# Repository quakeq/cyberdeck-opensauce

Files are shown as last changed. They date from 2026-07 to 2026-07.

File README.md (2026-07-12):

# cyberdeck-opensauce
repo for my cyberdeck project for hackclub opensauce. I made this because I wanted to make an useable cyberdeck that would be genuinely really nice to have daily.

## Demo
https://drive.google.com/file/d/1zyx6e2210Nebm2rjT3ZHg2T8rBJLfXjD/view?usp=sharing

## features
- Storage for all your goodies
- Custom Battery with 10 hr lifespan
- Mechanical keyboard that's removable for access to wires and stuff.
- Watersealed Case
- 10.1 inch touchscreen
- 2 USB ports and 1 ethernet

## Some images of the design and final product:





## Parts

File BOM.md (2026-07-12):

| Name | Quantity | Links |
|---|---|---|
| 10.1 DSI screen | 1 | https://www.waveshare.com/10.1inch-dsi-lcd-c.htm |
| Raspberry Pi 5 | 1 | https://www.raspberrypi.com/products/raspberry-pi-5/ |
| Raspberry Pico | 1 | https://www.raspberrypi.com/products/raspberry-pi-pico/ |
| Kalih Choc V1 Switches | 62 | https://chosfox.com/products/kailh-chocs |
| 18650 3450mah batteries | 12 | https://www.18650batterystore.com/products/panasonic-ncr18650ga-ga6 |
| 60 amp bms (any amp above 10 will work) | 1 | https://www.amazon.com/Cermant-Balance-Charger-Protection-Charging/dp/B0CZ73S26M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 |
| Female to Male Right Angle USB A | 2 | https://www.adafruit.com/product/6004 |
| Female to Male Ethernet | 1 | https://thepihut.com/products/panel-mount-ethernet-rj45-extension-cable |
| Buck Converter | 1 | https://www.amazon.com/DROK-Adjustable-Converter-Transformer-Protective/dp/B07JZ2GQJF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 |
| DSI cable | 1 | https://thepihut.com/products/display-adapter-cable-for-raspberry-pi-5 |
| Jumper Cables | 2 | IDK I had some lying around |
| 12 AWG wire | 1 | https://www.amazon.com/VIABRICO-Electrical-Conductors-Lighting-Extension/dp/B0CXJLNCGP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 |
| Power Switch | 1 | https://www.amazon.com/DaierTek-Rocker-Switch-Lighted-Motorcycle/dp/B0C1N8Y86Z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 
| Pelican Case | 1 | https://www.amazon.com/HUL-Professional-Cosmetic-Storage-Organizer/dp/B0827NJYD8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 |

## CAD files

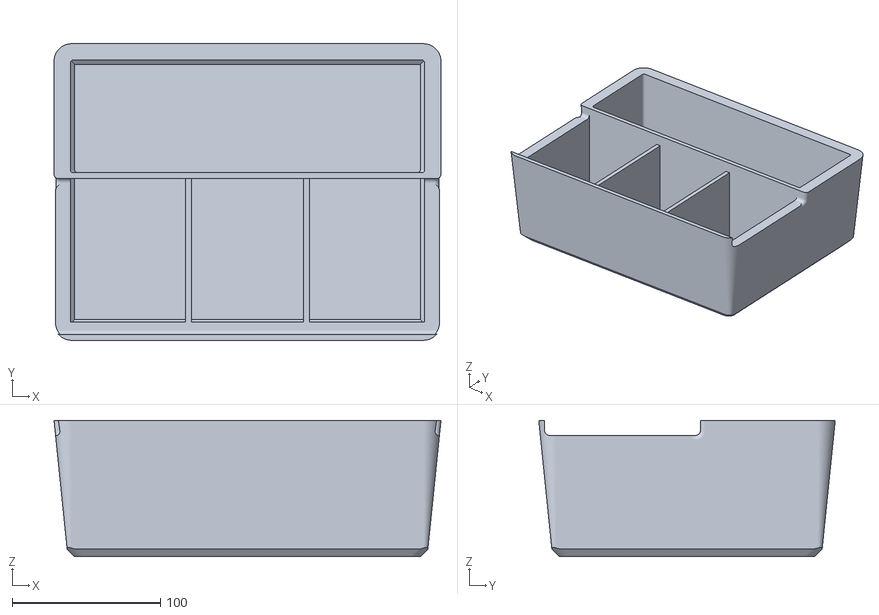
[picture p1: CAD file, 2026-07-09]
stl/cyberdeck/bottom case(9).stl
261.0 x 200.0 x 91.8

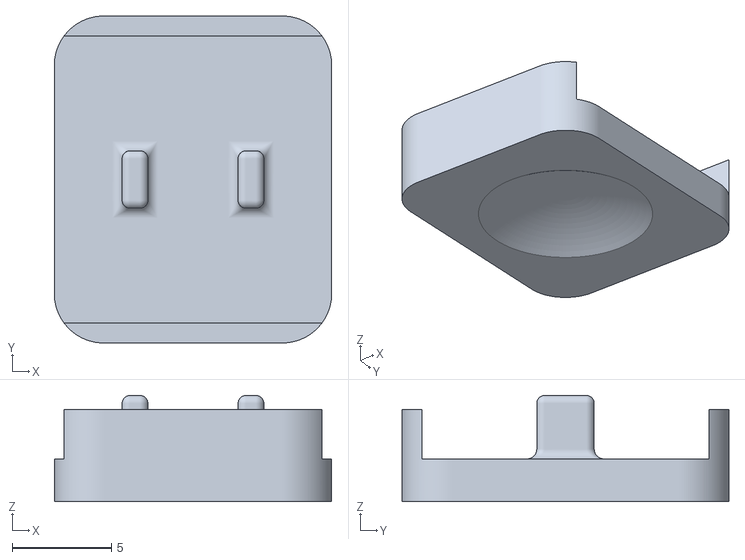
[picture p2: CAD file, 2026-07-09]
stl/keyboard/keycaps 0.8(1).stl
14.0 x 16.5 x 5.35

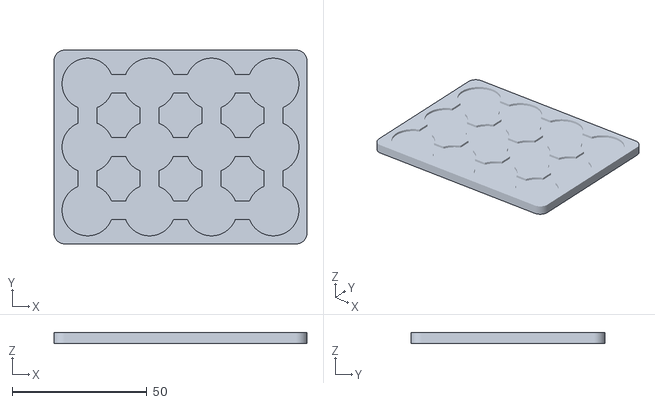
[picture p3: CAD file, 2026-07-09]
stl/cyberdeck/batterycover.stl
94.0 x 72.0 x 4.00

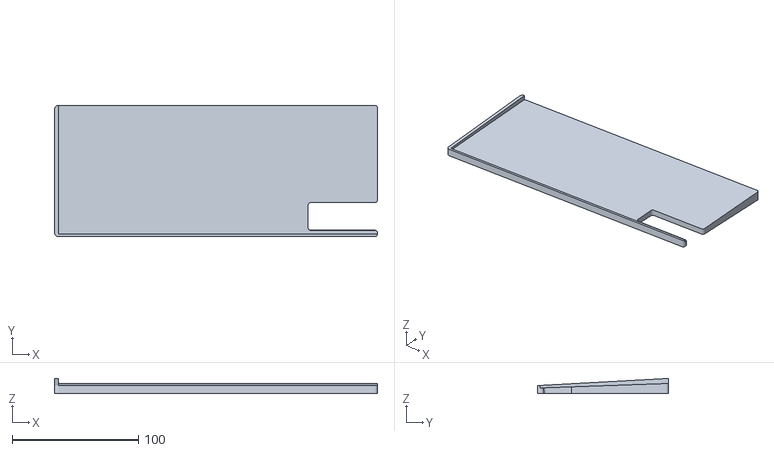
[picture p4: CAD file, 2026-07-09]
stl/keyboard/keyboard(6).stl
256.0 x 104.0 x 12.0

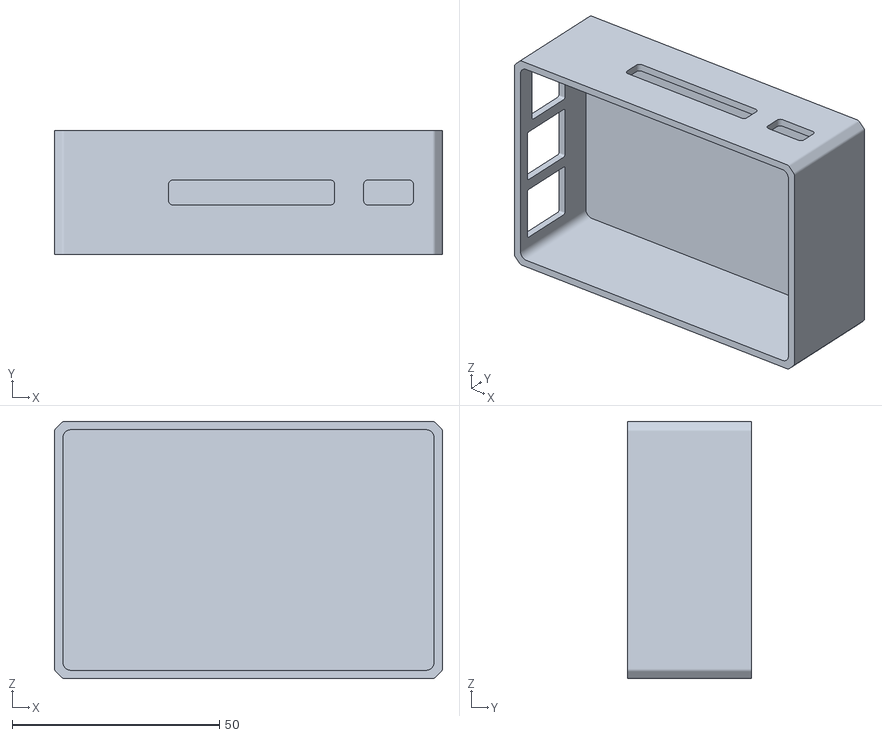
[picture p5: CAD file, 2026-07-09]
stl/cyberdeck/picase(3).stl
93.5 x 30.0 x 62.0

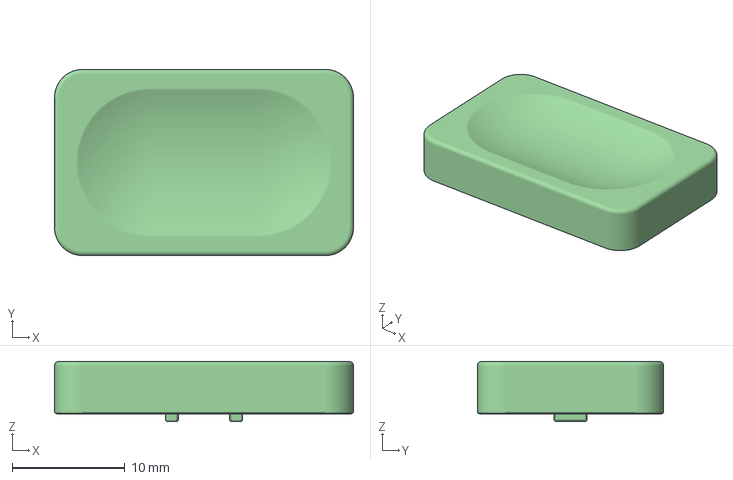
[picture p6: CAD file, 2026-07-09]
stl/keyboard/1.5u_c.3mf
26.5 x 16.5 x 5.35 mm

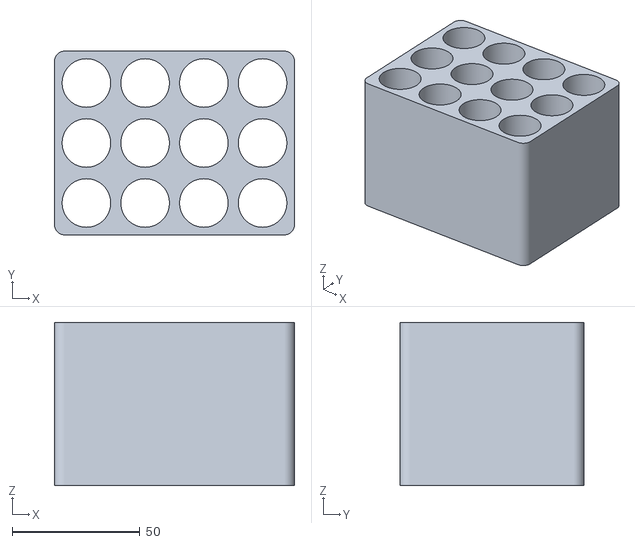
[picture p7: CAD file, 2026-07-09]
stl/cyberdeck/batterycase.stl
94.0 x 72.0 x 64.0

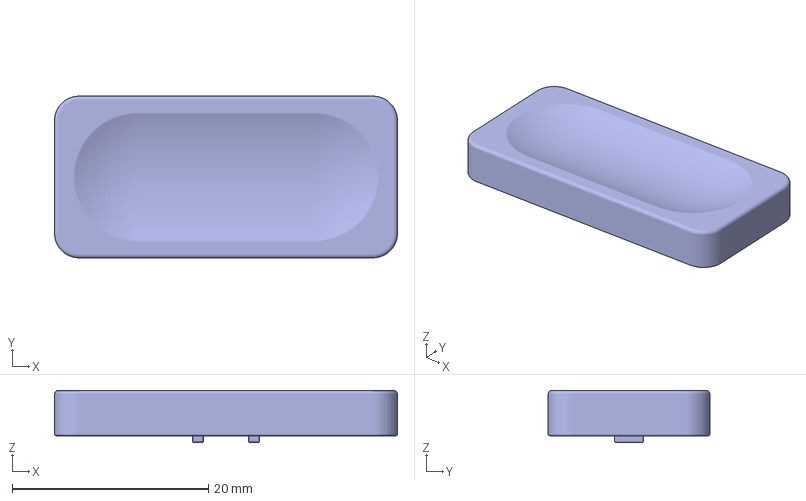
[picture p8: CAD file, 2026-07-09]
stl/keyboard/2u_c.3mf
35.0 x 16.5 x 5.35 mm

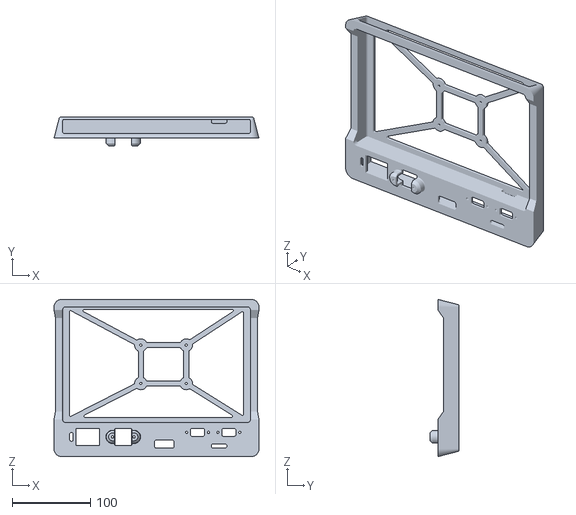
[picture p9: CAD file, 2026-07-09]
stl/cyberdeck/frontCoverv6.stl
262.0 x 37.0 x 201.0

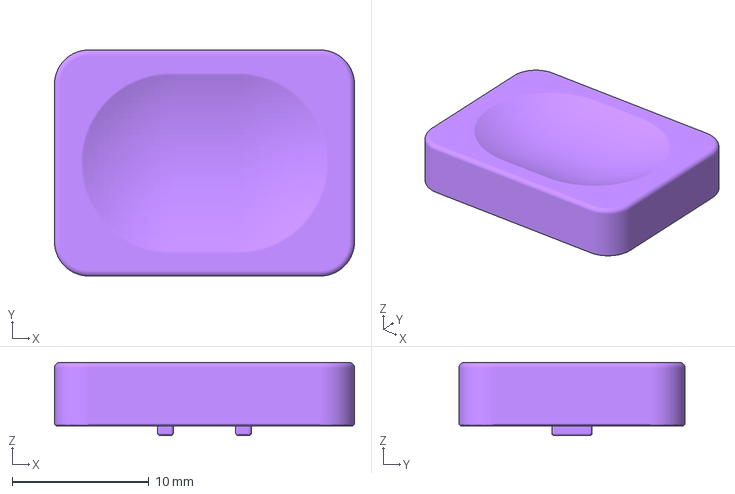
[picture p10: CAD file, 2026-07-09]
stl/keyboard/1.25u_c.3mf
21.9 x 16.5 x 5.35 mm

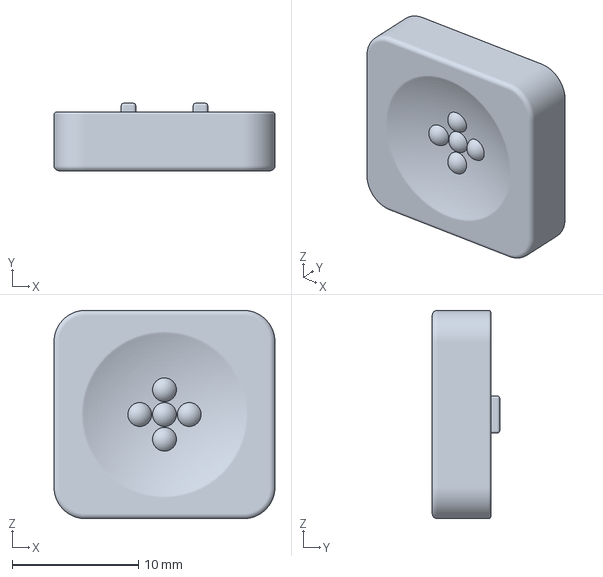
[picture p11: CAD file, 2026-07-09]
stl/keyboard/1u_choc_with_homing(1).3mf
17.5 x 5.35 x 16.5 mm

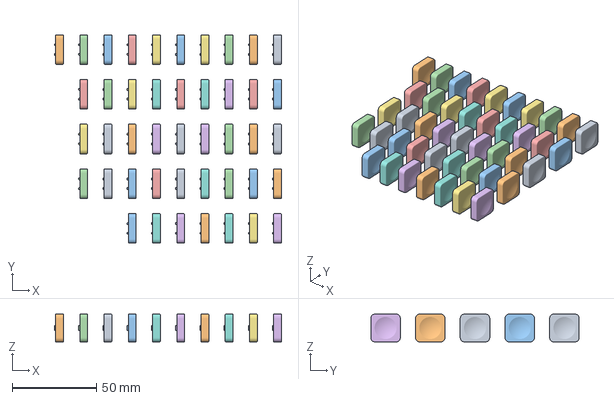
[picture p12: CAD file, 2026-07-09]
stl/keyboard/1u_c.3mf
134.5 x 123.5 x 16.5 mm
1u_c x 44

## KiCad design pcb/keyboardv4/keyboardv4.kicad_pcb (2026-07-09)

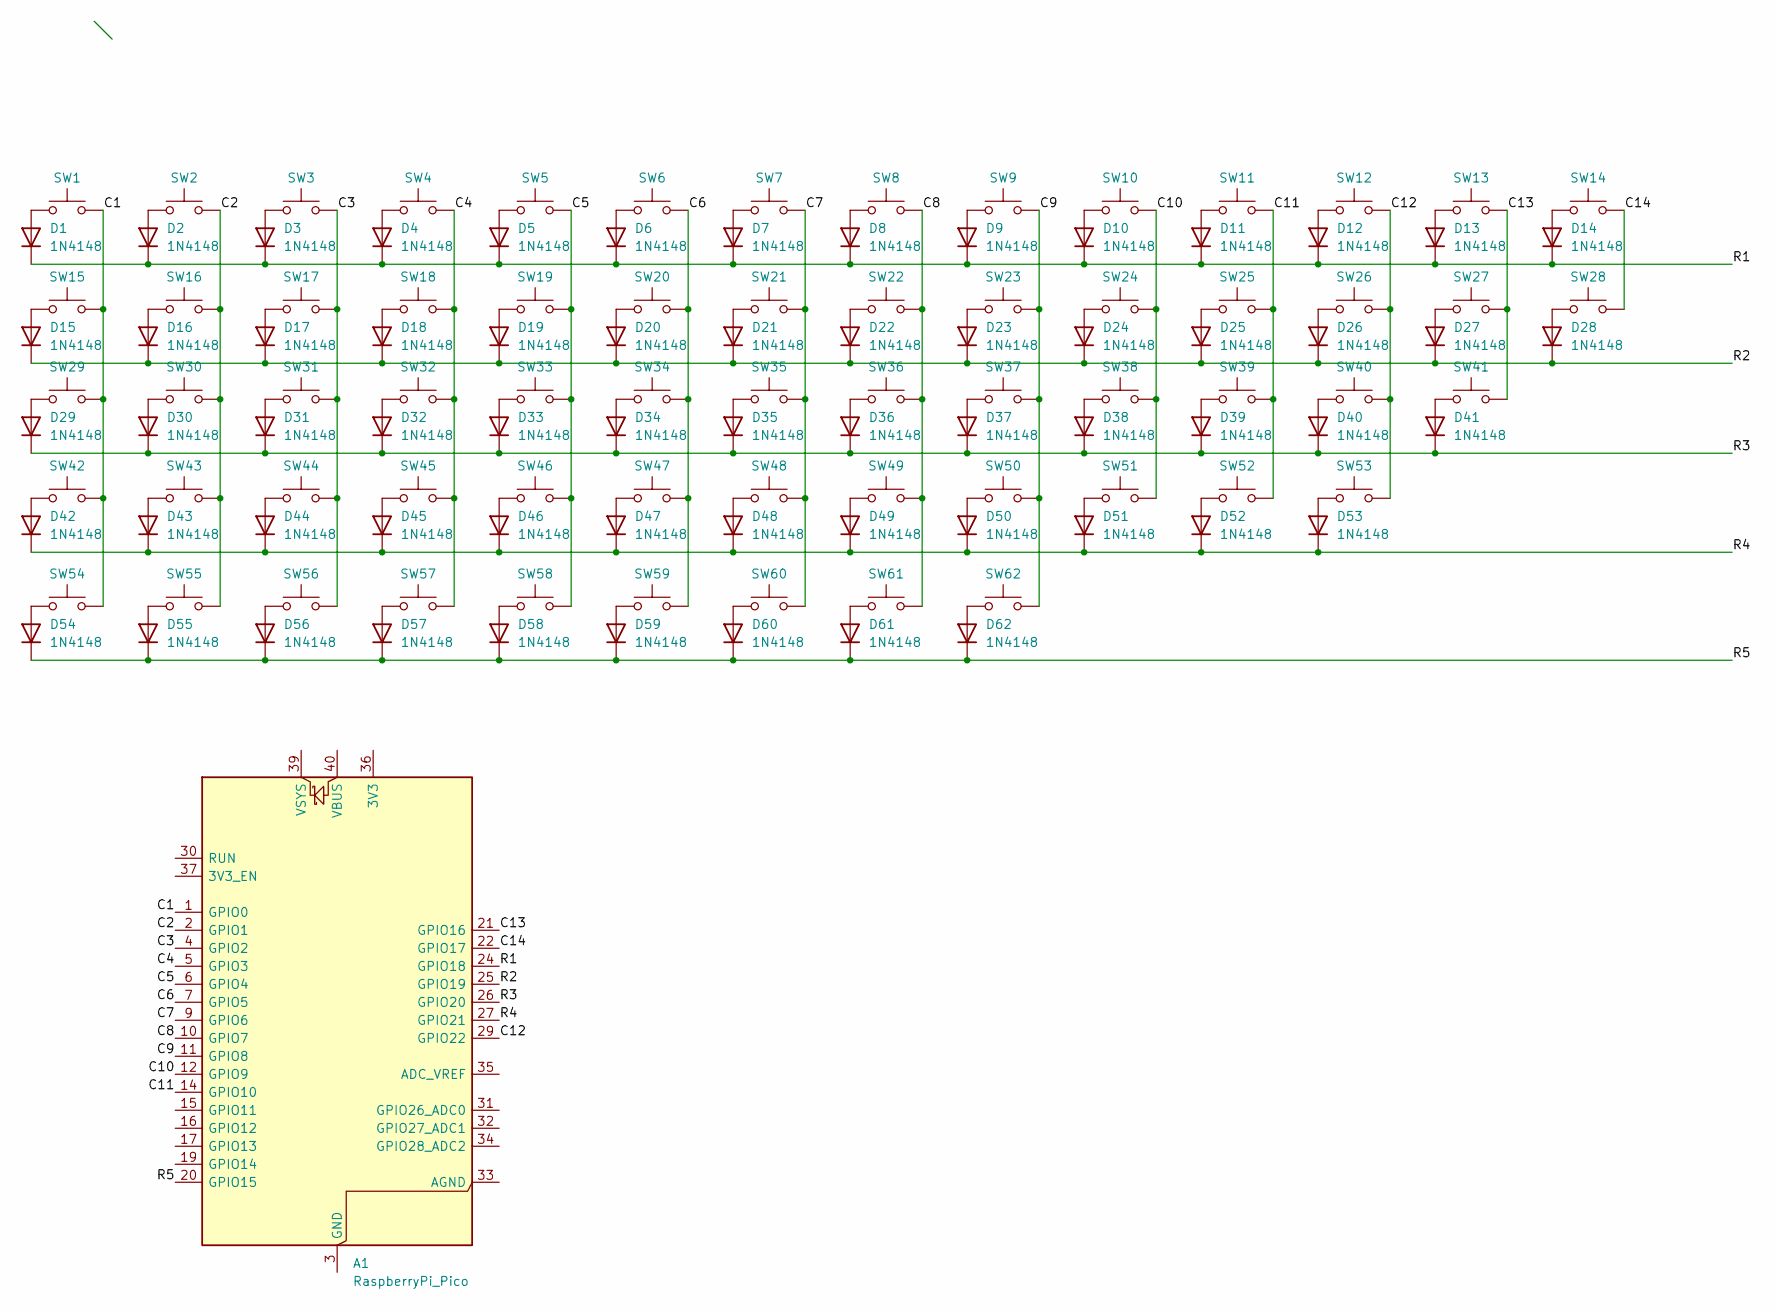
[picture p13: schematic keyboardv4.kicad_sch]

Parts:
A1: RaspberryPi_Pico; RaspberryPi_Pico_Common_Unspecified
D1, D2, D3, D4, D5, D6, D7, D8, D9, D10, D11, D12, D13, D14, D15, D16, D17, D18, D19, D20, D21, D22, D23, D24, D25, D26, D27, D28, D29, D30, D31, D32, D33, D34, D35, D36, D37, D38, D39, D40, D41, D42, D43, D44, D45, D46, D47, D48, D49, D50, D51, D52, D53, D54, D55, D56, D57, D58, D59, D60, D61, D62: 1N4148; D_DO-35_SOD27_P7.62mm_Horizontal
SW1, SW2, SW3, SW4, SW5, SW6, SW7, SW8, SW9, SW10, SW11, SW12, SW13, SW14, SW15, SW16, SW17, SW18, SW19, SW20, SW21, SW22, SW23, SW24, SW25, SW26, SW27, SW28, SW29, SW30, SW31, SW32, SW33, SW34, SW35, SW36, SW37, SW38, SW39, SW40, SW41, SW42, SW43, SW44, SW45, SW46, SW47, SW48, SW49, SW50, SW51, SW52, SW53, SW54, SW55, SW56, SW57, SW58, SW59, SW60, SW61, SW62: Momentary Tactile Button - Black; SW_PG1350

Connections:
/C1: A1.1 (GPIO0), SW1.2, SW15.2, SW29.2, SW42.2, SW54.2
/C2: A1.2 (GPIO1), SW2.2, SW16.2, SW30.2, SW43.2, SW55.2
/C3: A1.4 (GPIO2), SW3.2, SW17.2, SW31.2, SW44.2, SW56.2
/C4: A1.5 (GPIO3), SW4.2, SW18.2, SW32.2, SW45.2, SW57.2
/C5: A1.6 (GPIO4), SW5.2, SW19.2, SW33.2, SW46.2, SW58.2
/C6: A1.7 (GPIO5), SW6.2, SW20.2, SW34.2, SW47.2, SW59.2
/C7: A1.9 (GPIO6), SW7.2, SW21.2, SW35.2, SW48.2, SW60.2
/C8: A1.10 (GPIO7), SW8.2, SW22.2, SW36.2, SW49.2, SW61.2
/C9: A1.11 (GPIO8), SW9.2, SW23.2, SW37.2, SW50.2, SW62.2
/C10: A1.12 (GPIO9), SW10.2, SW24.2, SW38.2, SW51.2
/C11: A1.14 (GPIO10), SW11.2, SW25.2, SW39.2, SW52.2
/C12: A1.29 (GPIO22), SW12.2, SW26.2, SW40.2, SW53.2
/C13: A1.21 (GPIO16), SW13.2, SW27.2, SW41.2
/C14: A1.22 (GPIO17), SW14.2, SW28.2
/R1: A1.24 (GPIO18), D1.1 (K), D2.1 (K), D3.1 (K), D4.1 (K), D5.1 (K), D6.1 (K), D7.1 (K), D8.1 (K), D9.1 (K), D10.1 (K), D11.1 (K), D12.1 (K), D13.1 (K), D14.1 (K)
/R2: A1.25 (GPIO19), D15.1 (K), D16.1 (K), D17.1 (K), D18.1 (K), D19.1 (K), D20.1 (K), D21.1 (K), D22.1 (K), D23.1 (K), D24.1 (K), D25.1 (K), D26.1 (K), D27.1 (K), D28.1 (K)
/R3: A1.26 (GPIO20), D29.1 (K), D30.1 (K), D31.1 (K), D32.1 (K), D33.1 (K), D34.1 (K), D35.1 (K), D36.1 (K), D37.1 (K), D38.1 (K), D39.1 (K), D40.1 (K), D41.1 (K)
/R4: A1.27 (GPIO21), D42.1 (K), D43.1 (K), D44.1 (K), D45.1 (K), D46.1 (K), D47.1 (K), D48.1 (K), D49.1 (K), D50.1 (K), D51.1 (K), D52.1 (K), D53.1 (K)
/R5: A1.20 (GPIO15), D54.1 (K), D55.1 (K), D56.1 (K), D57.1 (K), D58.1 (K), D59.1 (K), D60.1 (K), D61.1 (K), D62.1 (K)
unnamed: A1.3 (GND), A1.8 (GND), A1.13 (GND), A1.18 (GND), A1.23 (GND), A1.28 (GND), A1.38 (GND)
unnamed: D1.2 (A), SW1.1
unnamed: D2.2 (A), SW2.1
unnamed: D3.2 (A), SW3.1
unnamed: D4.2 (A), SW4.1
unnamed: D5.2 (A), SW5.1
unnamed: D6.2 (A), SW6.1
unnamed: D7.2 (A), SW7.1
unnamed: D8.2 (A), SW8.1
unnamed: D9.2 (A), SW9.1
unnamed: D10.2 (A), SW10.1
unnamed: D11.2 (A), SW11.1
unnamed: D12.2 (A), SW12.1
unnamed: D13.2 (A), SW13.1
unnamed: D14.2 (A), SW14.1
unnamed: D15.2 (A), SW15.1
unnamed: D16.2 (A), SW16.1
unnamed: D17.2 (A), SW17.1
unnamed: D18.2 (A), SW18.1
unnamed: D19.2 (A), SW19.1
unnamed: D20.2 (A), SW20.1
unnamed: D21.2 (A), SW21.1
unnamed: D22.2 (A), SW22.1
unnamed: D23.2 (A), SW23.1
unnamed: D24.2 (A), SW24.1
unnamed: D25.2 (A), SW25.1
unnamed: D26.2 (A), SW26.1
unnamed: D27.2 (A), SW27.1
unnamed: D28.2 (A), SW28.1
unnamed: D29.2 (A), SW29.1
unnamed: D30.2 (A), SW30.1
unnamed: D31.2 (A), SW31.1
unnamed: D32.2 (A), SW32.1
unnamed: D33.2 (A), SW33.1
unnamed: D34.2 (A), SW34.1
unnamed: D35.2 (A), SW35.1
unnamed: D36.2 (A), SW36.1
unnamed: D37.2 (A), SW37.1
unnamed: D38.2 (A), SW38.1
unnamed: D39.2 (A), SW39.1
unnamed: D40.2 (A), SW40.1
unnamed: D41.2 (A), SW41.1
unnamed: D42.2 (A), SW42.1
unnamed: D43.2 (A), SW43.1
unnamed: D44.2 (A), SW44.1
unnamed: D45.2 (A), SW45.1
unnamed: D46.2 (A), SW46.1
unnamed: D47.2 (A), SW47.1
unnamed: D48.2 (A), SW48.1
unnamed: D49.2 (A), SW49.1
unnamed: D50.2 (A), SW50.1
unnamed: D51.2 (A), SW51.1
unnamed: D52.2 (A), SW52.1
unnamed: D53.2 (A), SW53.1
unnamed: D54.2 (A), SW54.1
unnamed: D55.2 (A), SW55.1
unnamed: D56.2 (A), SW56.1
unnamed: D57.2 (A), SW57.1
unnamed: D58.2 (A), SW58.1
unnamed: D59.2 (A), SW59.1
unnamed: D60.2 (A), SW60.1
unnamed: D61.2 (A), SW61.1
unnamed: D62.2 (A), SW62.1

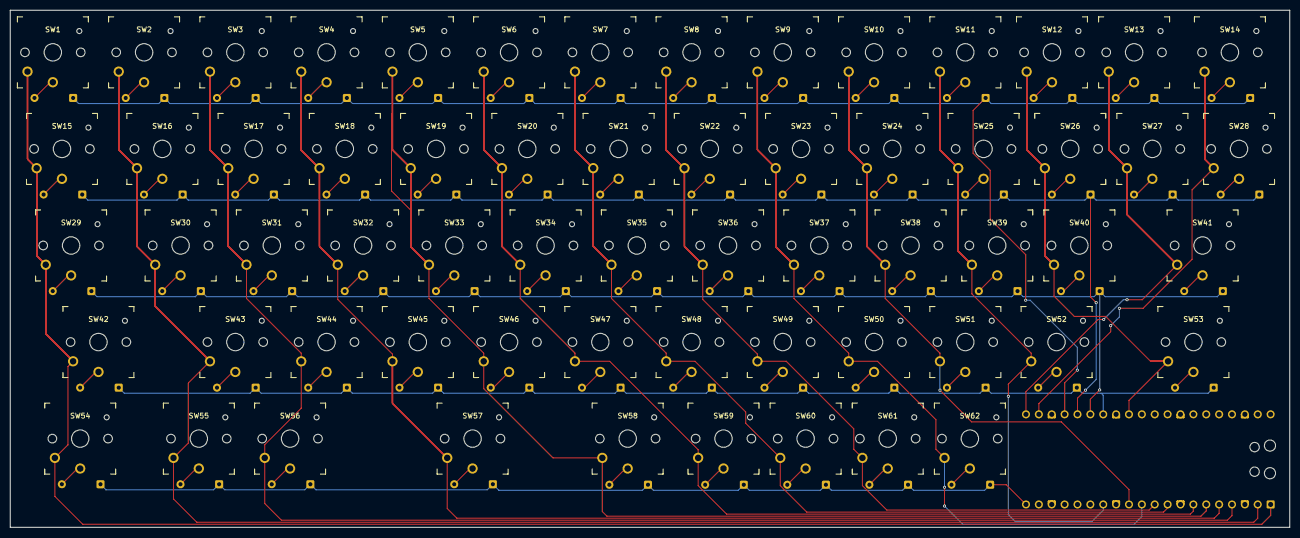
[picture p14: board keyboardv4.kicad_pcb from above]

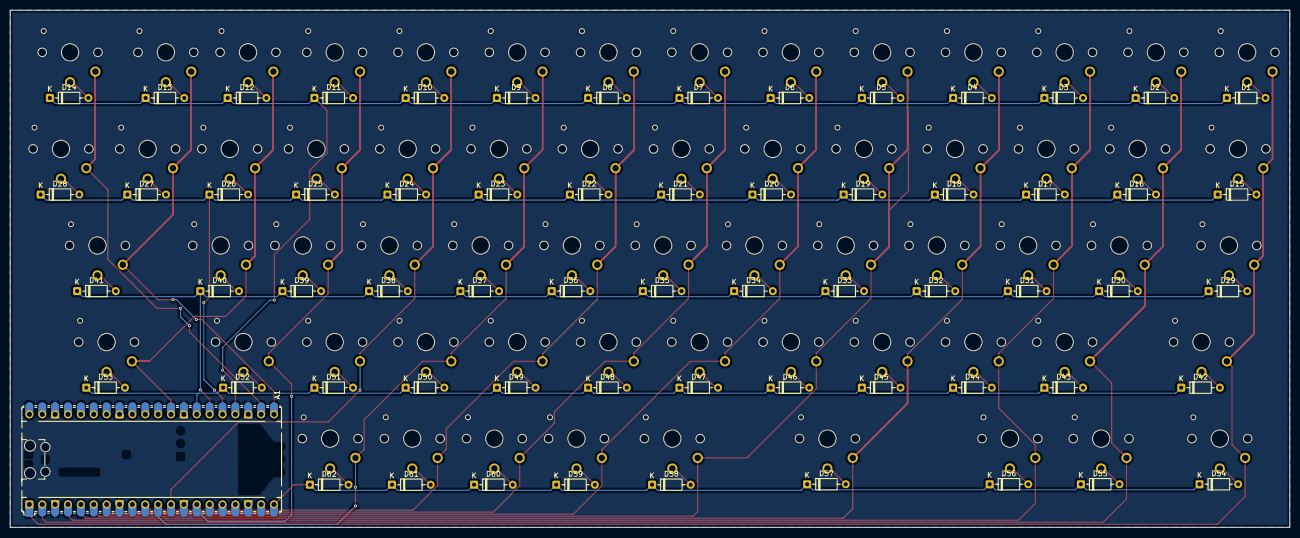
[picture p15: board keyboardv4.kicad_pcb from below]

Board: 2 copper layers, 252.4 x 102.0 mm, 125 parts (63 on the bottom side), 82 nets.

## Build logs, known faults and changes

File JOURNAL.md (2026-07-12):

# May 22th, 2026: Keyboard PCB + Screen Ordered

I finally got around to learning KiCad... 

I started out with looking at https://youtu.be/8WXpGTIbxlQ?si=HWInNqnCrlnGG9be to learn how to use KiCad to make the keyboard

I finished my layout for the switches. Time to start working on the wireless aspect of the keyboard!
The final idea is to have the keyboard be removable from the main body so that I can store RJ45 (Ethernet) cables and whatnot inside, so BT/wireless will be needed

The requirement of wireless pushed me to the ESP32 as it has built in BT. I already have some lying around too which is nice.

To figure out the battery, I looked at https://youtu.be/POPvclRAKOQ?si=WiUL5QYuJIJgOxCi and https://docs.google.com/viewerng/viewer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
The video was to figure out the recharging aspect of the keyboard, the second was to figure out how to actually get power from the battery.

Today's Schematic and PCB Layout:
2026-05-22--22:12:51

2026-05-22--22:12:41

Still need to figure out my key layout and to confirm that my battery routing makes sense.

I also ordered my screens from PiHut, arriving Wednesday. (5/27/26)

**Total time spent: 4h**

# May 25th, 2026: Almost done with keyboard layout!

I forgot to complete this journal the last two days, so this update is from the 23rd to the 25th

I updated my fill zones for power to be larger since that's better for power transfer apparently. I made my top layer fully VOUT (battery power) and my bottom layer GND  for that reason. My other zones might need to be updated but from what I see they're fine for now.

Images of power fill zones: 
2026-05-25--20:31:05

I also finished my layout and routing for the keys. I decided on an ortholinear layout since I want it to be as small as possible. I think there's optimizations that I can do to reduce the size of the keyboard but that's a problem for later.

2026-05-25--20:26:37

Todo: 
1. Fix all the DRC issues that popped up
2. Figure out where to place my delete key

**Total time spent: 3h**

# June 3rd, 2026: Done with keyboard layout (hopefully)

I finally got around to finishing the keyboard (why does school exist?)

I swapped out my esp32-D to the esp32-S3-mini since I saw that it was better for keyboards. I also ran DRC and fixed all the issues that popped up

I also gave up having a delete key, my reasoning was to just go the macbook route and bind Fn+Backspace to be delete.

Finished keyboard: !!!
2026-06-03--17:48:57

**Total Time spent: 3h**

# June 13th, 2026: Starting on cyberdeck body

We got our slides, got our screen, and so we can start working on the body of the actual deck! 

Onshape Workspace: https://cad.onshape.com/documents/1a1af402c0db1dda2c82ecab/w/3b0ea689bfd63b2e225e5440/e/0cdd63c72fabe09441a14d1b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 

I started with this inital design for the front back piece: 


I 3d printed it out and I found that it was lacking in sizing, it was way too large to really fit any common box form factor. I also found that it would look super weird since I would have like 2.75 inches of bezel at the bottom... (yikes!)

I thus redesigned to 1) have my casing dimensions in mind when designing and to also 2) have the bezel and appearance in mind as well.

Case: https://www.amazon.com/HUL-Professional-Cosmetic-Storage-Organizer/dp/B0827NJYD8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 

(I didn't really want to go with the pure 3d print case as to me that doesn't really feel "cyberdecky")

Redesign back panel v2:


PCB update:
I was using my other laptop to design my pcb keyboard, and I was an freaking idiot as I didn't make any backups on my ssd for the pcb and I also didn't upload to github my gerbers AND I switched distros to arch from nixos since I couldn't install tooling on nixos because of packaging issues. TLDR; I LOST ALL OF MY PCB FILES :D

**Total Time spent: 2h**

# Continued on Stardance: https://stardance.hackclub.com/projects/20067
